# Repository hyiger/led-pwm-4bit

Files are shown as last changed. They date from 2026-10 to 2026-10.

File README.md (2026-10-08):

# led-pwm-4bit

A 40 × 30 mm two-layer board that dims a 24 V LED strip to one of 16 levels set by
four open-drain outputs of a Prusa GPIO Hackerboard. An ATtiny412 reads the 4-bit
word and drives a low-side N-MOSFET with 10-bit PWM at about 2.4 kHz.

KiCad 10 project. The design brief is [docs/spec.md](docs/spec.md) and the
reference netlist is [docs/netlist.txt](docs/netlist.txt).

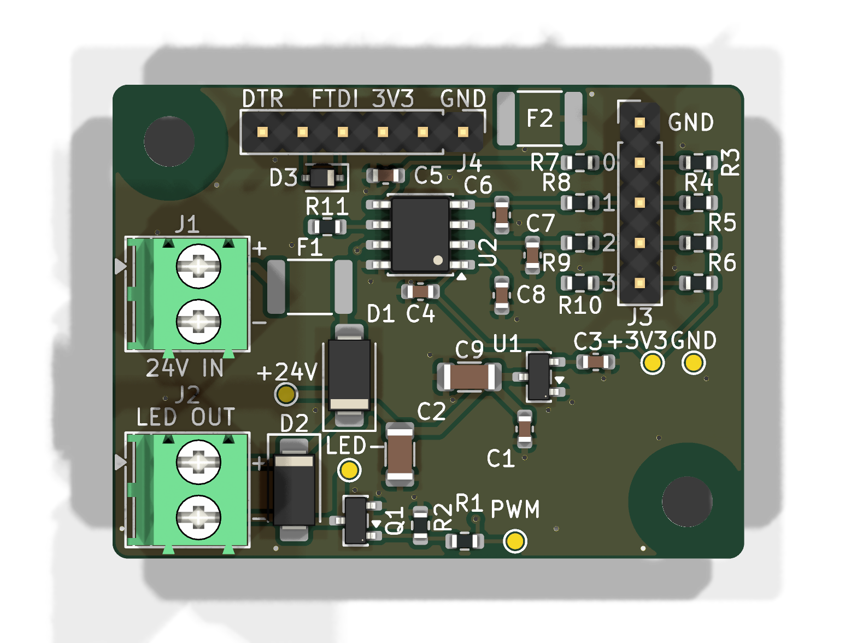
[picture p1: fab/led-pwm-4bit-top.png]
Top render


## Status

| Step | State |
|---|---|
| Schematic | Done. ERC: 0 violations. `check_netlist.py`: matches `docs/netlist.txt` |
| Placement | Done. Schematic parity clean |
| Routing | In progress. DRC: 0 violations; 5 unrouted connections (three `HB_GND` links to F2, UPDI_BUS R11–D3, SEL3 C8–R10). GND pours stitched with 32 vias |
| Parts | Every line has a manufacturer part carried by Mouser; see [Parts](#parts) |
| Firmware | Not started (spec section 9) |

## Files

| Path | Contents |
|---|---|
| `led-pwm-4bit.kicad_pro` | Project: JLCPCB constraints, net classes (Default, Power) |
| `led-pwm-4bit.kicad_sch` | Schematic, one sheet, KiCad standard symbols only |
| `led-pwm-4bit.kicad_pcb` | Board |
| `led-pwm-4bit.kicad_dru` | Custom DRC rules (JLCPCB limits, 0.5 mm power tracks) |
| `check_netlist.py` | Compares the schematic netlist with `docs/netlist.txt` |
| `scripts/export-fab.sh` | Runs ERC, netlist check and DRC, then writes `fab/` |
| `fab/` | Schematic PDF, BOM, Mouser order CSV, position file, renders; Gerbers once DRC is clean |

## Parts

All parts are chosen from manufacturers Mouser stocks, and each was checked against
its manufacturer's datasheet for package, pinout and ratings. Capacitor values were
also checked against DC-bias data.
`fab/led-pwm-4bit-bom.csv` is the full BOM and `fab/led-pwm-4bit-mouser-order.csv`
is in Mouser's BOM-tool format (`BOARDS=n scripts/export-fab.sh` scales it). The
order rounds the resistors, capacitors and D3 up to at least 10 with spares, which
costs less than the exact count at Mouser's single-piece prices.

The Mouser part-number column is left empty on purpose. Mouser blocks automated
access, so no Mouser number could be read off its live listing, and a guessed
number can import cleanly and still be the wrong part. Mouser's BOM tool matches
each line on the manufacturer part number instead. Once a Mouser number is
confirmed, add a field named `Mouser` to that symbol and the export carries it.

| Ref | Part | Notes |
|---|---|---|
| U1 | Microchip MCP1792T-3302H/CB | 55 V input LDO, SOT-23A |
| U2 | Microchip ATTINY412-SSN | Tube; ATtiny212-SSN also fits |
| Q1 | ROHM RTR030N05HZGTL | 45 V, RDS(on) ≤ 95 mΩ at VGS 2.5 V. The 60 V IRLML0060 is not rated below 4.5 V gate drive |
| D1, D2 | Diodes Inc B160-13-F | 60 V 1 A Schottky, SMA |
| D3 | onsemi BAT54HT1G | SOD-323, pin 1 cathode (BAT54J is out of stock at Mouser) |
| F1 | Littelfuse 1812L050/60MR | 0.5 A hold, 60 V, Imax 10 A |
| F2 | Bel Fuse 0ZCG0010FF2C | 0.1 A hold, 60 V, Imax 100 A; Hackerboard/programmer ground return |
| C1 | Murata GRM188R61H225KE11D | 2.2 µF 50 V X5R 0603, about 0.4 µF at 24 V |
| C2, C9 | Murata GRM31CR71H475MA12L | 4.7 µF 50 V X7R 1206, about 2.7 µF each at 24 V |
| C3 | Samsung CL10A106MP8NQWC | 10 µF 10 V X5R 0603, about 5.9 µF at 3.3 V |
| C4 | KEMET C0603C104K5RACTU | 100 nF 50 V X7R |
| C5–C8 | KEMET C0603C103K5RACTU | 10 nF 50 V X7R |
| R1–R11 | YAGEO RC0603FR-07…L | 1 % 0603; R3–R10 are all 10 kΩ |
| J1, J2 | Phoenix Contact 1984617 | PT 1,5/2-3,5-H, the part the footprint is drawn for |
| J3 | Würth 61300511121 | 1×5 2.54 mm header |
| J4 | Würth 61300611121 | 1×6 2.54 mm header |

No 10 µF 50 V X7R in 1206 was in stock at Mouser. The Murata 4.7 µF X7R keeps more
capacitance at 24 V than any 10 µF 1206 part Mouser stocks.

## Routing notes

- The Power net class (`+24V_IN`, `VIN_F`, `+24V`, `LED_NEG`, `GND`) defaults to
  0.5 mm, and DRC rejects anything narrower. Signals default to 0.25 mm.
- Rule areas keep tracks off B.Cu under Q1 and U2, so the bottom pour stays whole
  there (spec section 8). Ground vias are still allowed.
- Return Q1's source (pin 2) straight to the GND pad of C2.
- The pours are stitched with 32 GND vias (0.6/0.3 mm, tented): one beside each
  GND pad, two between C9 and U1, plus a sparse 8 mm grid. The +24V and +3V3
  tracks split the top pour into regions joined only by thin necks, and the vias
  tie every region to the bottom pour. The vias stay clear of the routes still to
  be drawn and of the mounting-hole keepout, and no via drill lands on
  silkscreen. A few via rings reach under the edge of a part outline; they are
  tented, so this is cosmetic.
- C6 pad 2 had only one thermal spoke because SEL1 and SEL2 crowd it. It now has a
  0.5 mm GND track to a via at (125.75, 108.75).
- `HB_GND` joins J3 pin 1, J4 pins 1–2 and F2 pad 1. A 0.25 mm track is enough,
  and it survives the brief fault current before F2 trips. J3.1 to J4.1 runs easily
  on B.Cu. Keep it out of the GND pour: F2 is the only connection between the two
  grounds.
- `scripts/export-fab.sh` refills the pours before its DRC, without saving the board.

## Wiring and mounting

- Fuse the 24 V feed at the source: a 2–3 A fast fuse (rated ≥ 32 V DC) in the +
  lead at the PSU or tap point, or a separate 1–2 A supply. F1 is rated to interrupt
  only 10 A and does not protect the J1 cable.
- Run the supply's − wire straight to J1 pin 2. Don't share it with the Hackerboard
  cable's ground, so only signal current flows through the Hackerboard ground.
- Check the strip wiring for a short between + and − before the first power-up.
- Mount the board on standoffs with nylon screws, or keep metal hardware away from any
  grounded frame. The mounting holes have no copper around them.
- Avoid hot-plugging J1 at 28 V with long leads (see Open items).

## Connectors

| | Pin 1 | Pin 2 | Pin 3 | Pin 4 | Pin 5 | Pin 6 |
|---|---|---|---|---|---|---|
| J1 24 V in | +24 V | GND | | | | |
| J2 LED strip | Strip + | Strip − | | | | |
| J3 Hackerboard J6 pins 1–5 | GND (via F2) | out0 | out1 | out2 | out3 | |
| J4 FTDI adapter | GND (via F2) | CTS (GND via F2) | VCC (n.c.) | TXD | RXD / UPDI | DTR (n.c.) |

Hackerboard J6 is a 1×10 2.54 mm footprint, usually bare holes. Its pin 1 is the
square pad by the `GND` label at the `0` end. A straight 1×5 cable from J6 pins 1–5
to J3 matches pin for pin.

## Flashing

J4 takes any USB-serial adapter in the standard FTDI pin order with **3.3 V logic**
(FT232R, CP2102, or a CH340 that really runs at 3.3 V). The SerialUPDI network
(D3 and R11) is on the board, so the adapter needs no modification.

1. Power the board from 24 V. J4's VCC pin is not connected.
2. Plug the adapter in with its GND on J4 pin 1 (the `GND` end of the header).
3. Flash with avrdude 8.x:

   ```bash
   avrdude -c serialupdi -p t412 -P /dev/cu.usbserial-XXXX -U flash:w:firmware.hex:i
   ```

   or pymcuprog:

   ```bash
   pymcuprog write -t uart -u /dev/cu.usbserial-XXXX -d attiny412 -f firmware.hex --erase --verify
   ```

Keep the default 115200 baud at 3.3 V. In the Arduino IDE with megaTinyCore, pick
"SerialUPDI - SLOW: 57600 baud", a 10 MHz clock and BOD 2.6 V. Never change the
UPDI/reset pin fuse: recovery would then need a 12 V programmer.

A Microchip programmer (Atmel-ICE, MPLAB SNAP, PICkit) connects to J4 pin 5 (UPDI)
and pin 1 (GND), with its target-voltage sense lead on TP2 (+3V3) and the board
powered from 24 V. Leave "power target from tool" off.

## Using it from the printer

```gcode
M267 R3 B0    ; once: all expander pins are outputs (firmware default)
M267 R1 B15   ; level 15 (full on); B0 = off, B1..B14 in between
```

The level persists in the printer's EEPROM. While the printer boots, or when the
cable is unplugged, the inputs float high and the strip is off.

## Checks

```bash
python3 check_netlist.py
```

```bash
scripts/export-fab.sh
```

The script runs ERC (`--severity-all --exit-code-violations`), the netlist check and
DRC with `--schematic-parity` after refilling the pours. It writes Gerbers and
separate plated and non-plated drill files only when DRC reports no violations and
no unrouted connections.

## Changes from spec Rev 0.1

- Resistors and small capacitors are 0603. The 47 µF electrolytic is replaced by two
  4.7 µF 50 V X7R 1206 MLCCs (C2, C9), because no 50 V bulk part exists in 0603.
- J4 is a 6-pin FTDI-style header with a SerialUPDI network (D3, R11 470 Ω)
  instead of a bare 3-pin UPDI header.
- SEL pins are permuted for a crossing-free layout: SEL0 = PA2, SEL1 = PA1,
  SEL2 = PA7, SEL3 = PA6. Section 6 of the spec allows this.
- Q1 is a ROHM RTR030N05HZGTL (45 V) instead of the AO3422 (55 V), which Mouser
  does not carry.
- F2 puts the Hackerboard and programmer grounds (net `HB_GND`) behind a 0.1 A PPTC,
  and R7–R10 are 10 kΩ instead of 1 kΩ.
- Board constraints follow JLCPCB's 2-layer 1 oz capabilities. The design net
  classes keep the spec's 0.2 mm clearance and 0.25 / 0.5 mm tracks.

## Open items

- **Reverse polarity with a shared ground.** D1 protects only the board's own +24V
  rail. If the supply shares ground with the printer and the J1 wires are swapped,
  board GND rises to supply +. F2 then trips and stops the short through the
  Hackerboard ground, and the 10 kΩ R7–R10 keep the current into the input pins to
  about 2.4 mA each. Two exposures remain:
  - The pull-ups R3–R6 draw up to about 11 mA out of +3V3, pulling it about 0.6 V
    below GND. That is past the U1 and U2 supply-pin limits. A Schottky clamp from GND
    to +3V3 would fix it.
  - A programming adapter plugged in at the same time sees 41–57 mA through R11, which
    burns R11 (0.8–1.5 W) and stresses U2's UPDI pin and the adapter. Check J1
    polarity before plugging in an adapter.
  A reverse-polarity MOSFET in the J1 return would remove both by keeping board GND
  from rising at all.
- **Strip short.** F1 protects the wiring and D1, not Q1. A short across J2 while the
  strip is lit can destroy Q1 (3 A continuous, 12 A for 10 µs). A failed Q1 usually
  shorts and leaves the strip on. Replace Q1 after any strip short.
- **Hot-plug overshoot.** The all-ceramic 24 V input rings when J1 is hot-plugged, and
  D1 holds the peak on +24V. At 24 V with leads of 2 m or less the first peak is about
  30–36 V. At 28 V with heavy leads and F1 near its minimum resistance it can reach
  45–50 V, above Q1's 45 V and the capacitors' 50 V rating. A 47 µF 50 V electrolytic
  on +24V would damp it to under 30 V.
- Prusa lists the Core One INDX as *not compatible* with the GPIO Hackerboard, although
  firmware 6.9.1 and 6.10.1 still enable the M262–M268 commands on it.
- JLCPCB charges a small-board fee when a side is 30 mm or less. 40 × 31 mm avoids it.

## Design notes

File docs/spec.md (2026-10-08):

# 4-Bit LED PWM Controller: KiCad Handoff Spec

Author: hyiger · Rev 0.4 · 2026-10-07

This is the complete brief for the KiCad project. The netlist in [`netlist.txt`](netlist.txt) is the source of truth; section 6 summarises it. Where this document and a datasheet disagree on a pin number, the datasheet wins: stop and report the conflict.

## 1. What to build

A small 2-layer board that dims a 24 V constant-voltage LED strip (about 120 mA) to one of 16 brightness levels. The level is a 4-bit word set by four open-drain outputs of a Prusa GPIO Hackerboard. An ATtiny412 reads the word and drives a low-side N-MOSFET with PWM.

```
24 V in ─ F1 ─ D1 ─┬──────────────── +24V ──── J2.1  strip +
                   ├─ C1, C2, C9                J2.2  strip − ─┐
                   └─ U1 (LDO) ─ +3V3 ─ U2 (ATtiny412)         │
Hackerboard pins 0–3 ─ J3 ─ pull-up + RC ─ U2 inputs           │
Hackerboard GND ─ J3.1 ─ F2 (PPTC) ─ board GND                  │
                                  U2 PA3 ─ R1 ─ gate Q1 ─ drain┘
USB-serial adapter ─ J4 ─ D3 + R11 (SerialUPDI) ─ U2 PA0/UPDI
```

The board takes only ground and four signals from the Hackerboard. It makes its own 3.3 V from the 24 V rail.

## 2. Hackerboard interface

- Pins 0–3 are open-drain N-MOSFET outputs (DMN3190LDW, 100 Ω gate resistor, 100 kΩ gate pull-down), rated by Prusa to switch 24 V at 500 mA to ground. They have no pull-ups, LEDs or clamps, so nothing on the Hackerboard can back-feed our 3.3 V pull-ups.
- Pins 4–7 are TCA6408A push-pull outputs at 3.3 V through 330 Ω (10 mA). This design does not use them.
- Logic is inverted at the wire: writing 1 turns the transistor on and pulls the pin to ground. Writing 0 leaves it floating.
- `M267 R1 B<0-255>` writes the whole output register in one I2C transaction. With the word on pins 0–3, `M267 R1 B0` to `M267 R1 B15` selects the level directly and all four bits change together. Bits 4–7 are written too.
- Run `M267 R3 B0` once so all pins are outputs (the firmware default). This also stops the 500 ms input polling that can trigger `btn_N` macros.
- Register values persist in the printer's EEPROM and are restored at boot. Until then the TCA6408A powers up with every pin as an input, so all four lines float and read as level 0.
- The Hackerboard must be connected when the printer boots; hot-plugging does not work.
- Connector: Hackerboard J6 is a 1×10 2.54 mm footprint, usually bare holes, so you will probably have to solder in a header. Its silkscreen reads `GND 7 6 5 4 3 2 1 0 GND`. Pin 1 is the square pad at the `0` end. J6 pins 1–5 carry GND, out0, out1, out2, out3 in that order and match J3 one to one.
- Out0–out2 also go to the Hackerboard's 2.5 mm "Shutter" jack. Leave that jack empty.
- Prusa's product page lists the Core One INDX as *not compatible* with the Hackerboard set, although firmware 6.9.1 and 6.10.1 still enable M262–M268 on COREONE_INDX. Check before relying on it with an INDX.

Consequence for this board: each input needs a pull-up to 3.3 V, and the firmware inverts the nibble. A disconnected or unpowered Hackerboard reads as 1111, which inverts to level 0, so the strip is off.

## 3. Electrical requirements

| Item | Requirement |
|---|---|
| Supply | 24 V DC nominal, 20–28 V operating, fused or current-limited at the source (2–3 A fast fuse rated ≥ 32 V DC, or a 1–2 A supply) |
| Load | Constant-voltage LED strip, 120 mA nominal; copper sized for 1 A |
| Switching | Low-side N-MOSFET, strip + tied to the protected 24 V rail |
| Levels | 16, gamma-corrected, level 0 fully off, level 15 fully on (100% duty) |
| PWM | 10-bit, about 2.44 kHz |
| Logic rail | 3.3 V from an on-board LDO, under 5 mA load |
| Default state | Strip off during reset, programming, and with inputs disconnected |
| Protection | Input fuse, reverse-polarity diode, clamp diode across the strip, PPTC in the Hackerboard/programmer ground return |
| Programming | SerialUPDI with any 3.3 V USB-serial adapter on J4, board powered from 24 V |

## 4. Circuit blocks

**Input and protection.** J1 → F1 (resettable fuse) → D1 (series Schottky, reverse-polarity protection) → `+24V`. F1 handles slow overloads: it holds 0.5 A, trips at 1 A, and needs up to 0.15 s at 8 A. It is rated to interrupt only 10 A, so the feed must be fused at the source (section 3); with that, D1 stays within its surge rating. F1 does not protect Q1: a short across J2 while the strip is lit can destroy Q1 before F1 trips. D1 protects only the board's own rail. When the supply shares ground with the printer, swapped J1 wires put supply + on board GND. The Hackerboard ground (J3 pin 1) and the programming adapter's ground (J4 pins 1 and 2) therefore reach board GND only through F2 (net `HB_GND`). F2 is a 0.1 A / 60 V PPTC rated to interrupt 100 A; its 1.6 Ω minimum resistance limits a 28 V short to 17.5 A until it trips. In normal use it carries only a few mA of signal return. Tripped, it still passes about 30 mA and leaves board GND up to 28 V above the printer's ground. C2 and C9 (4.7 µF 50 V X7R 1206 MLCCs, about 2.7 µF each at 24 V) are the bulk capacitance. C2 sits in the PWM loop beside Q1 and J2; C9 sits at U1's input. With no electrolytic, F1's resistance is the only damping of hot-plug ringing on the input, and D1 holds the peak on `+24V`. At 24 V with leads of 2 m or less the first peak is about 30–36 V. At 28 V with heavy leads and F1 near its 0.15 Ω minimum it can reach 45–50 V, above Q1's 45 V and the MLCCs' 50 V rating. A 47 µF 50 V electrolytic with 0.3–1 Ω ESR on `+24V` would hold it near 28 V.

**3.3 V rail.** U1 is an MCP1792-3302 (55 V input, 70 V transient, 100 mA) in SOT-23A. C1 is its input capacitor and C3 its output capacitor. All passives except C2 and C9 (1206) are 0603. The datasheet requires at least 2.2 µF of ceramic on the output and recommends 3.3 µF: C3 (10 µF 10 V X5R) keeps about 5.9 µF at 3.3 V. It recommends 2.2–10 µF on the input. No 0603 part rated 50 V holds much at 24 V: C1 (2.2 µF 50 V X5R) keeps about 0.4 µF, and C9 beside it adds about 2.7 µF. Dissipation is about (28 − 3.3) V × 5 mA ≈ 124 mW at the 28 V maximum, or 104 mW at 24 V nominal.

**MCU.** U2 is an ATtiny412 in SOIC-8, running at 10 MHz from its internal oscillator. C4 decouples it.

**Inputs.** Each of the four lines has a 10 kΩ pull-up to `+3V3` on the connector side, then 10 kΩ in series, then 10 nF to ground at the MCU pin (100 µs). With all four lines low the pull-ups draw 1.3 mA. The 10 kΩ series resistors also limit the current into the MCU pins to about 2.4 mA each if F2 trips and the board ground is lifted 24 V above the Hackerboard's. In that fault the pull-ups also draw up to about 11 mA out of `+3V3`, pulling it about 0.6 V below GND, past the U1 (−0.3 V) and U2 (−0.5 V) supply-pin limits (section 12).

**Output stage.** U2 PA3 → R1 (100 Ω) → gate of Q1. R2 (100 kΩ) holds the gate low while PA3 is high-impedance. Q1 is a ROHM RTR030N05HZGTL (45 V, RDS(on) ≤ 95 mΩ at VGS = 2.5 V, 3 A, TSMT3 on the SOT-23 land): about 11 mV drop and 1.4 mW at 120 mA. Its 45 V rating is the lowest on the 24 V side; the AO3422 (55 V) is not sold by Mouser, and no 55–60 V SOT-23 part in stock there has RDS(on) specified at 3.3 V or below. D2 clamps the drain to `+24V` to absorb wiring inductance.

**Programming.** J4 is a 6-pin FTDI-style header, numbered from the adapter's side. The adapter's TXD (pin 4) reaches the UPDI line through D3, a Schottky with its cathode toward TXD. The adapter's RXD (pin 5) connects to the UPDI line directly. R11 (470 Ω) sits between that line and PA0/UPDI. GND (pin 1) and CTS (pin 2) go to `HB_GND`, the ground behind F2, so CTS is asserted on adapters that enable handshaking by default. VCC (pin 3) is not connected, because some 3.3 V-logic adapters put 5 V there. DTR (pin 6) is not connected. A dedicated UPDI programmer uses pin 5 (UPDI) and pin 1 (GND). Microchip tools (Atmel-ICE, MPLAB SNAP, PICkit) also need their target-voltage sense lead on +3V3 (TP2), with the board powered from 24 V and "power target from tool" off.

## 5. BOM

All parts come from manufacturers Mouser stocks. Each was checked against its manufacturer's datasheet, and the capacitors against DC-bias data. Mouser availability was read from oemstrade.com on 2026-10-07, because Mouser blocks automated access. No Mouser part number is recorded until it has been read off its live listing; the order CSV matches on manufacturer part numbers.

| Ref | Manufacturer part | Package | Notes |
|---|---|---|---|
| U1 | Microchip MCP1792T-3302H/CB | SOT-23A-3 | Pin 1 GND, 2 VOUT, 3 VIN |
| U2 | Microchip ATTINY412-SSN | SOIC-8 (3.9 mm) | Tube. ATtiny212-SSN also fits |
| Q1 | ROHM RTR030N05HZGTL | TSMT3 (SOT-23 land) | Pin 1 G, 2 S, 3 D. 45 V, ≤ 95 mΩ at 2.5 V |
| D1, D2 | Diodes Inc B160-13-F | SMA | 60 V 1 A Schottky |
| D3 | onsemi BAT54HT1G | SOD-323 | Pin 1 K, 2 A. 30 V |
| F1 | Littelfuse 1812L050/60MR | 1812 | 0.5 A hold, 1 A trip, 60 V, Imax 10 A |
| F2 | Bel Fuse 0ZCG0010FF2C | 1812 | 0.1 A hold, 0.3 A trip, 60 V, Imax 100 A, Rmin 1.6 Ω. Fallback Bourns MF-MSMF010/60X-2 (40 A) |
| C1 | Murata GRM188R61H225KE11D, 2.2 µF 50 V X5R | 0603 | U1 input, about 0.4 µF at 24 V |
| C2, C9 | Murata GRM31CR71H475MA12L, 4.7 µF 50 V X7R | 1206 | Bulk, about 2.7 µF each at 24 V |
| C3 | Samsung CL10A106MP8NQWC, 10 µF 10 V X5R | 0603 | U1 output, about 5.9 µF at 3.3 V |
| C4 | KEMET C0603C104K5RACTU, 100 nF 50 V X7R | 0603 | U2 decoupling |
| C5–C8 | KEMET C0603C103K5RACTU, 10 nF 50 V X7R | 0603 | Input filters |
| R1 | YAGEO RC0603FR-07100RL, 100 Ω 1% | 0603 | Gate series |
| R2 | YAGEO RC0603FR-07100KL, 100 kΩ 1% | 0603 | Gate pull-down |
| R3–R6 | YAGEO RC0603FR-0710KL, 10 kΩ 1% | 0603 | Input pull-ups |
| R7–R10 | YAGEO RC0603FR-0710KL, 10 kΩ 1% | 0603 | Input series |
| R11 | YAGEO RC0603FR-07470RL, 470 Ω 1% | 0603 | UPDI series |
| J1, J2 | Phoenix Contact 1984617 (PT 1,5/2-3,5-H) | THT | 24 V in, strip out |
| J3 | Würth 61300511121, 1×5 2.54 mm | THT | Hackerboard |
| J4 | Würth 61300611121, 1×6 2.54 mm | THT | FTDI / SerialUPDI |
| TP1–TP5 | Test point | 1 mm pad | +24V, +3V3, GND, PWM, LED− |
| H1, H2 | M3 mounting hole, 3.2 mm | NPTH | No net |

Diode pin numbers follow the KiCad convention: pin 1 cathode, pin 2 anode.

## 6. Netlist

[`netlist.txt`](netlist.txt) lists every net. `check_netlist.py` compares the schematic against it. Compared with Rev 0.1:

```netlist
+24V:     ... C2.1 C9.1 ...         (C9 added)
UPDI:     U2.6 R11.2
UPDI_BUS: J4.5 R11.1 D3.2
UPDI_TX:  J4.4 D3.1
GND:      ... C2.2 C9.2 ... F2.2 ...  (J3.1, J4.1, J4.2 moved to HB_GND)
HB_GND:   J3.1 J4.1 J4.2 F2.1      (J4.2 = CTS)
+3V3:     ... (J4 no longer on +3V3)
NC:       J4.3 J4.6
SEL0:     R7.2 C5.1 U2.5         (PA2)
SEL1:     R8.2 C6.1 U2.4         (PA1)
SEL2:     R9.2 C7.1 U2.3         (PA7)
SEL3:     R10.2 C8.1 U2.2        (PA6)
```

U2 pin map (ATtiny412 SOIC-8): 1 VDD, 2 PA6, 3 PA7, 4 PA1, 5 PA2, 6 PA0/UPDI, 7 PA3, 8 GND. `PWM` stays on PA3 (TCA0 WO0, the default pin; the alternate is PA7).

## 7. Connectors

| Connector | Pin 1 | Pin 2 | Pin 3 | Pin 4 | Pin 5 | Pin 6 |
|---|---|---|---|---|---|---|
| J1, 24 V in | +24 V | GND | | | | |
| J2, strip | Strip + | Strip − | | | | |
| J3, Hackerboard J6 pins 1–5 | GND (through F2) | Pin 0 (bit 0) | Pin 1 (bit 1) | Pin 2 (bit 2) | Pin 3 (bit 3) | |
| J4, FTDI adapter | GND (through F2) | CTS (to GND through F2) | VCC (n.c.) | TXD (adapter out) | RXD (adapter in) = UPDI | DTR (n.c.) |

Program with the board powered from 24 V. Never connect the board's 3.3 V to the adapter's VCC.

## 8. PCB constraints

- 2 layers, 1.6 mm FR4, 1 oz copper, outline 40 × 30 mm, two M3 holes with no copper within 3.75 mm of their centres, so metal mounting hardware cannot reach board GND. JLCPCB adds a small-board fee when a side is 30 mm or less; 40 × 31 mm avoids it.
- Board Setup > Constraints holds JLCPCB's 2-layer 1 oz absolute minimums: 0.10 mm clearance, track and connection width, 0.05 mm via annular ring, 0.25 mm via diameter, 0.15 mm drill, 0.2 mm hole-to-hole, 0.2 mm copper-to-hole, 0.2 mm copper-to-edge, silk text 1.0 mm high with 0.15 mm stroke. Solder mask: 0 expansion, 0.1 mm minimum web, 0.09 mm mask to copper.
- `led-pwm-4bit.kicad_dru` adds the JLCPCB limits those fields cannot express: PTH ring ≥ 0.18 mm, PTH hole to copper ≥ 0.28 mm, pad hole to hole ≥ 0.45 mm, NPTH ≥ 0.5 mm, pad to silkscreen ≥ 0.15 mm.
- Net classes carry the design values. Default: 0.2 mm clearance, 0.25 mm track, 0.6/0.3 mm via. Power (`+24V_IN`, `VIN_F`, `+24V`, `LED_NEG`, `GND`): 0.5 mm track, enforced as a DRC minimum.
- Ground pour on both layers, stitched with vias. Rule areas keep tracks off B.Cu under Q1 and U2 so the bottom pour stays unbroken there.
- Keep the PWM current loop small: C2, J2, Q1 and D2 together, with Q1's source returning to C2's negative pin by the shortest path.
- C1 within 3 mm of U1 pin 3. C3 within 3 mm of U1 pin 2. C4 directly at U2 pins 1 and 8. C5–C8 at the U2 pins, R3–R6 near J3.
- J1 and J2 on one edge, J3 on the opposite edge, J4 on the top edge for the adapter.
- Silkscreen: polarity at J1 and J2, `GND 0 1 2 3` at J3, adapter pin names at J4, board name, revision, and "hyiger".

## 9. Firmware contract (phase 2)

- Clock: internal 20 MHz oscillator, prescaler 2, giving 10 MHz. This is the limit at 3.3 V. The part starts at 20 MHz / 6 after reset.
- BOD: BODLEVEL2 (2.6 V). The 10 MHz speed grade is guaranteed only down to that level. Never use 4.2 V; chip erase would then fail at 3.3 V.
- Fuses: never change SYSCFG0.RSTPINCFG from UPDI. GPIO or RESET locks out SerialUPDI, and recovery then needs a 12 V high-voltage programmer.
- PWM: TCA0 single-slope on WO0 (PA3), PORTMUX.CTRLC = 0, prescaler 4, PER = 1022. Frequency is 10 MHz / 4 / 1023 = 2444 Hz. A compare value of 1023 gives a constant high output. Do not use split mode.
- Inputs: PA2, PA1, PA7, PA6 as plain inputs (external pull-ups, internal ones off). PA0 stays UPDI.
- Mapping: SEL0 = PA2, SEL1 = PA1, SEL2 = PA7, SEL3 = PA6.
- Level: `level = ~(bit3..bit0) & 0x0F`, with bit 0 = SEL0.
- Debounce: sample every 1 ms and apply a new level only after 20 identical consecutive samples.
- Start-up: set compare to 0 before enabling the PA3 output.
- Lookup table (gamma 2.2, 10-bit):

```c
static const uint16_t LUT[16] = {
    0, 3, 12, 30, 56, 91, 136, 191, 257, 333, 419, 517, 626, 747, 879, 1023
};
```

Level 1 is a 1.2 µs pulse. If it is unstable or invisible on the real strip, raise `LUT[1]` or use a larger timer prescaler. The hardware does not change.

Flashing with avrdude 8.x (7.x chip-erases on every flash write):

```
avrdude -c serialupdi -p t412 -P <port> -U flash:w:firmware.hex:i
```

Keep the default 115200 baud at 3.3 V. In the Arduino IDE with megaTinyCore, use "SerialUPDI - SLOW: 57600 baud", a 10 MHz clock and BOD 2.6 V.

## 10. KiCad workflow and deliverables

1. Target the installed KiCad, checked with `kicad-cli version` (10.0.7).
2. Project name `led-pwm-4bit`. Every symbol and footprint comes from the KiCad standard libraries with pin numbers checked against the datasheets (Q1 uses `Transistor_FET:Q_NMOS_GSD`: 1 G, 2 S, 3 D).
3. `check_netlist.py` exports the netlist with `kicad-cli sch export netlist` and compares it to `netlist.txt`. It must match exactly: same nets, same pins, nothing extra.
4. `kicad-cli sch erc --severity-all --exit-code-violations` and `kicad-cli pcb drc --schematic-parity --severity-all` must report zero violations.
5. Review points: after the schematic passes ERC and the netlist check; after placement; after routing passes DRC.
6. `scripts/export-fab.sh` writes the outputs to `fab/`: schematic PDF, BOM, Mouser BOM-tool order CSV, position file, top and bottom renders, and, once DRC is clean, Gerbers and separate PTH/NPTH drill files zipped for upload.

## 11. Acceptance checks

- Exported netlist equals `netlist.txt`. ERC and DRC report zero violations.
- No unconnected pins except J4.3 and J4.6, which carry no-connect flags. No pin on more than one net.
- Every polarized part (D1, D2, D3, Q1, U1, U2) has its pin 1 checked against the datasheet and the footprint.
- With U2 removed or in reset, `GATE` is held at 0 V by R2.
- Voltage ratings: everything on `+24V_IN`, `VIN_F`, `+24V` or `LED_NEG` is rated at least 35 V.

## 12. Open items

Resolved:

- Reverse polarity through a shared ground: F2 in the J3/J4 ground return (section 4), with R7–R10 raised to 10 kΩ.
- Hackerboard connector: J6, 1×10 2.54 mm. Pins 1–5 = GND, 0, 1, 2, 3, so J3 is a 1×5 2.54 mm header.
- TCA0 WO0 defaults to PA3 (ATtiny212/412 datasheet DS40002287A, Table 5-2 and PORTMUX.CTRLC).
- F1: Littelfuse 1812L050/60MR (60 V, 0.5 A hold).
- Q1 pin order: ROHM's RTR030N05HZG datasheet gives (1) Gate, (2) Source, (3) Drain.

Still open:

- Core One INDX compatibility of the Hackerboard (see section 2).
- Mouser part numbers: to be read off Mouser's live listings, or resolved by uploading the order CSV to Mouser's BOM tool.
- With F2 tripped the board ground floats up to 28 V above the printer's. R7–R10 limit the input pins to about 2.4 mA each, but:
  - the pull-ups R3–R6 pull `+3V3` about 0.6 V below GND at up to 11 mA. A low-VF Schottky from GND to `+3V3` (Microchip DS20006229 section 4.4) would clamp it;
  - a programming adapter on J4 at the same time sees 41–57 mA through R11 and D3. That burns R11 (0.8–1.5 W) and drives U2's UPDI pin below GND. Check J1 polarity before plugging in an adapter.
  A low-side reverse-polarity MOSFET in the J1 return would stop board GND rising at all and remove both cases.
- A short across J2 while Q1 conducts can destroy Q1 before F1 trips; a failed Q1 usually shorts and leaves the strip on. Check the strip wiring before the first power-up and replace Q1 after any strip short.
- Hot-plug overshoot at 28 V with heavy leads can exceed Q1's 45 V (section 4). Avoid hot-plugging J1 at 28 V, or add a damped electrolytic.
- Bel's 100 A rating for F2 is unusually high for its size (Littelfuse's equivalent is rated 10 A at 60 V); Bel's datasheet, product page and the Fuzetec original all state 100 A. The Bourns fallback is rated 40 A.
- Strip current: above 0.5 A, F1 and D1 have to change.
- Where the 24 V comes from. If it is not the printer's own supply, the two grounds still have to be common through J3 pin 1. Run the supply's − wire straight to J1 pin 2 and keep it separate from the Hackerboard cable's ground, so only signal current flows through the Hackerboard ground.

Left out on purpose: a TVS on the 24 V input (an SMAJ28A-class part still lets 44–47 V through at 28 V, so it would not protect Q1), a status LED (no spare MCU pin), and any isolation between the printer and the strip.

## 13. Sources

- Prusa help article "GPIO Hackerboard" and schematic FDM-MK4-Gpio-02 (BOM05): connector, output stage, G-code.
- Prusa-Firmware-Buddy v6.9.1/v6.10.1, `src/marlin_stubs/M262-M268.cpp`, `src/hw/TCA6408A.cpp`: M267 behaviour and EEPROM persistence.
- Microchip DS20006229D, MCP1792/3: SOT-23A pinout, capacitor requirements, 4.5–55 V input.
- ROHM RTR030N05HZG datasheet Rev.001: 45 V, RDS(on) ≤ 95 mΩ at VGS = 2.5 V, ±12 V gate, pinout.
- Murata, Samsung and KEMET DC-bias data for C1, C2/C9 and C3.
- Microchip DS40002287A, ATtiny212/214/412/414/416: pinout, multiplexing, speed grades, UPDI.
- JLCPCB PCB capabilities page (checked 2026-10-07).
- SpenceKonde AVR-Guidance `UPDI/jtag2updi.md` and the avrdude 8.3 manual: SerialUPDI wiring and commands.

## Revision history

- 0.4 (2026-10-07): F2 (PPTC) in the Hackerboard and programmer ground return (net `HB_GND`); R7–R10 raised to 10 kΩ; copper keepout around the mounting holes; source fusing required; fault limits documented after an adversarial review.
- 0.3 (2026-10-07): Parts sourced from Mouser (Q1 ROHM RTR030N05HZGTL, D3 BAT54HT1G on SOD-323, F1 Littelfuse, J1/J2 Phoenix 1984617, Würth headers, Yageo/KEMET/Murata/Samsung passives); the 47 µF electrolytic replaced by C2 and C9 (4.7 µF 50 V X7R 1206); JLCPCB assembly files dropped.
- 0.2 (2026-10-07): 0603 passives throughout; J4 changed to an FTDI-style SerialUPDI header with D3 and R11; SEL pins permuted for routing; JLCPCB rules; parts selected with LCSC numbers; open items from 0.1 resolved.
- 0.1 (2026-10-07): first handoff.

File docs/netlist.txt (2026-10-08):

# Reference netlist for led-pwm-4bit. check_netlist.py compares the
# schematic's exported netlist against this file.
#
# Format: NET: REF.PIN ...   Every pin of every part except H1 and H2
# appears exactly once. "NC:" lists pins that must stay unconnected.
#
# Differs from spec Rev 0.1 section 6 in four places:
# - The Hackerboard and programming-adapter grounds (J3.1, J4.1, J4.2) reach
#   board GND through F2, a PPTC that opens if J1 is wired backwards while
#   the supply shares ground with the printer.
# - The 47 uF electrolytic C2 is replaced by two 1206 MLCCs, C2 and C9.
# - J4 is a 6-pin FTDI-style header with an on-board SerialUPDI network
#   (D3, R11) instead of a 3-pin UPDI header.
# - SEL0..SEL3 use the permutation section 6 allows, so the four input
#   rows from J3 reach U2 without crossing: SEL0 = PA2, SEL1 = PA1,
#   SEL2 = PA7, SEL3 = PA6.

+24V_IN: J1.1 F1.1
VIN_F:   F1.2 D1.2
+24V:    D1.1 C1.1 C2.1 C9.1 U1.3 D2.1 J2.1 TP1.1
GND:     J1.2 C1.2 C2.2 C9.2 U1.1 C3.2 C4.2 U2.8 R2.2 Q1.2 F2.2 C5.2 C6.2 C7.2 C8.2 TP3.1
HB_GND:  J3.1 J4.1 J4.2 F2.1
+3V3:    U1.2 C3.1 C4.1 U2.1 R3.1 R4.1 R5.1 R6.1 TP2.1
UPDI:     U2.6 R11.2
UPDI_BUS: J4.5 R11.1 D3.2
UPDI_TX:  J4.4 D3.1
PWM:     U2.7 R1.1 TP4.1
GATE:    R1.2 R2.1 Q1.1
LED_NEG: Q1.3 D2.2 J2.2 TP5.1
IN0:     J3.2 R3.2 R7.1
IN1:     J3.3 R4.2 R8.1
IN2:     J3.4 R5.2 R9.1
IN3:     J3.5 R6.2 R10.1
SEL0:    R7.2 C5.1 U2.5
SEL1:    R8.2 C6.1 U2.4
SEL2:    R9.2 C7.1 U2.3
SEL3:    R10.2 C8.1 U2.2
NC:      J4.3 J4.6

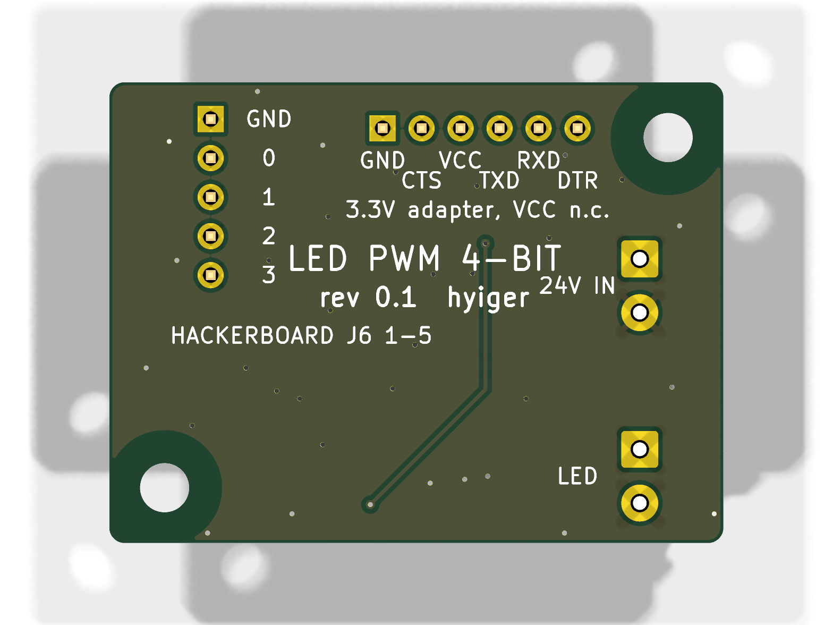
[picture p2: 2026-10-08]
fab/led-pwm-4bit-bottom.png

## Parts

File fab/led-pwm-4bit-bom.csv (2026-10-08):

Reference | Value | Footprint | Manufacturer | MPN | Mouser | Qty
C1 | 2.2u 50V X5R | Capacitor_SMD:C_0603_1608Metric | Murata | GRM188R61H225KE11D |  | 1
C2,C9 | 4.7u 50V X7R | Capacitor_SMD:C_1206_3216Metric | Murata | GRM31CR71H475MA12L |  | 2
C3 | 10u 10V X5R | Capacitor_SMD:C_0603_1608Metric | Samsung | CL10A106MP8NQWC |  | 1
C4 | 100n 50V X7R | Capacitor_SMD:C_0603_1608Metric | KEMET | C0603C104K5RACTU |  | 1
C5-C8 | 10n 50V X7R | Capacitor_SMD:C_0603_1608Metric | KEMET | C0603C103K5RACTU |  | 4
D1,D2 | B160 | Diode_SMD:D_SMA | Diodes Inc | B160-13-F |  | 2
D3 | BAT54HT1G | Diode_SMD:D_SOD-323 | onsemi | BAT54HT1G |  | 1
F1 | 0.5A 60V | Fuse:Fuse_1812_4532Metric | Littelfuse | 1812L050/60MR |  | 1
F2 | 0.1A 60V | Fuse:Fuse_1812_4532Metric | Bel Fuse | 0ZCG0010FF2C |  | 1
J1 | 24V IN | TerminalBlock_Phoenix:TerminalBlock_Phoenix_PT-1,5-2-3.5-H_1x02_P3.50mm_Horizontal | Phoenix Contact | 1984617 |  | 1
J2 | LED STRIP | TerminalBlock_Phoenix:TerminalBlock_Phoenix_PT-1,5-2-3.5-H_1x02_P3.50mm_Horizontal | Phoenix Contact | 1984617 |  | 1
J3 | HACKERBOARD | Connector_PinHeader_2.54mm:PinHeader_1x05_P2.54mm_Vertical | Wurth Elektronik | 61300511121 |  | 1
J4 | FTDI-UPDI | Connector_PinHeader_2.54mm:PinHeader_1x06_P2.54mm_Vertical | Wurth Elektronik | 61300611121 |  | 1
Q1 | RTR030N05HZG | Package_TO_SOT_SMD:SOT-23 | ROHM | RTR030N05HZGTL |  | 1
R1 | 100 | Resistor_SMD:R_0603_1608Metric | YAGEO | RC0603FR-07100RL |  | 1
R2 | 100k | Resistor_SMD:R_0603_1608Metric | YAGEO | RC0603FR-07100KL |  | 1
R3-R10 | 10k | Resistor_SMD:R_0603_1608Metric | YAGEO | RC0603FR-0710KL |  | 8
R11 | 470 | Resistor_SMD:R_0603_1608Metric | YAGEO | RC0603FR-07470RL |  | 1
U1 | MCP1792T-3302H/CB | Package_TO_SOT_SMD:SOT-23 | Microchip | MCP1792T-3302H/CB |  | 1
U2 | ATtiny412-SSN | Package_SO:SOIC-8_3.9x4.9mm_P1.27mm | Microchip | ATTINY412-SSN |  | 1

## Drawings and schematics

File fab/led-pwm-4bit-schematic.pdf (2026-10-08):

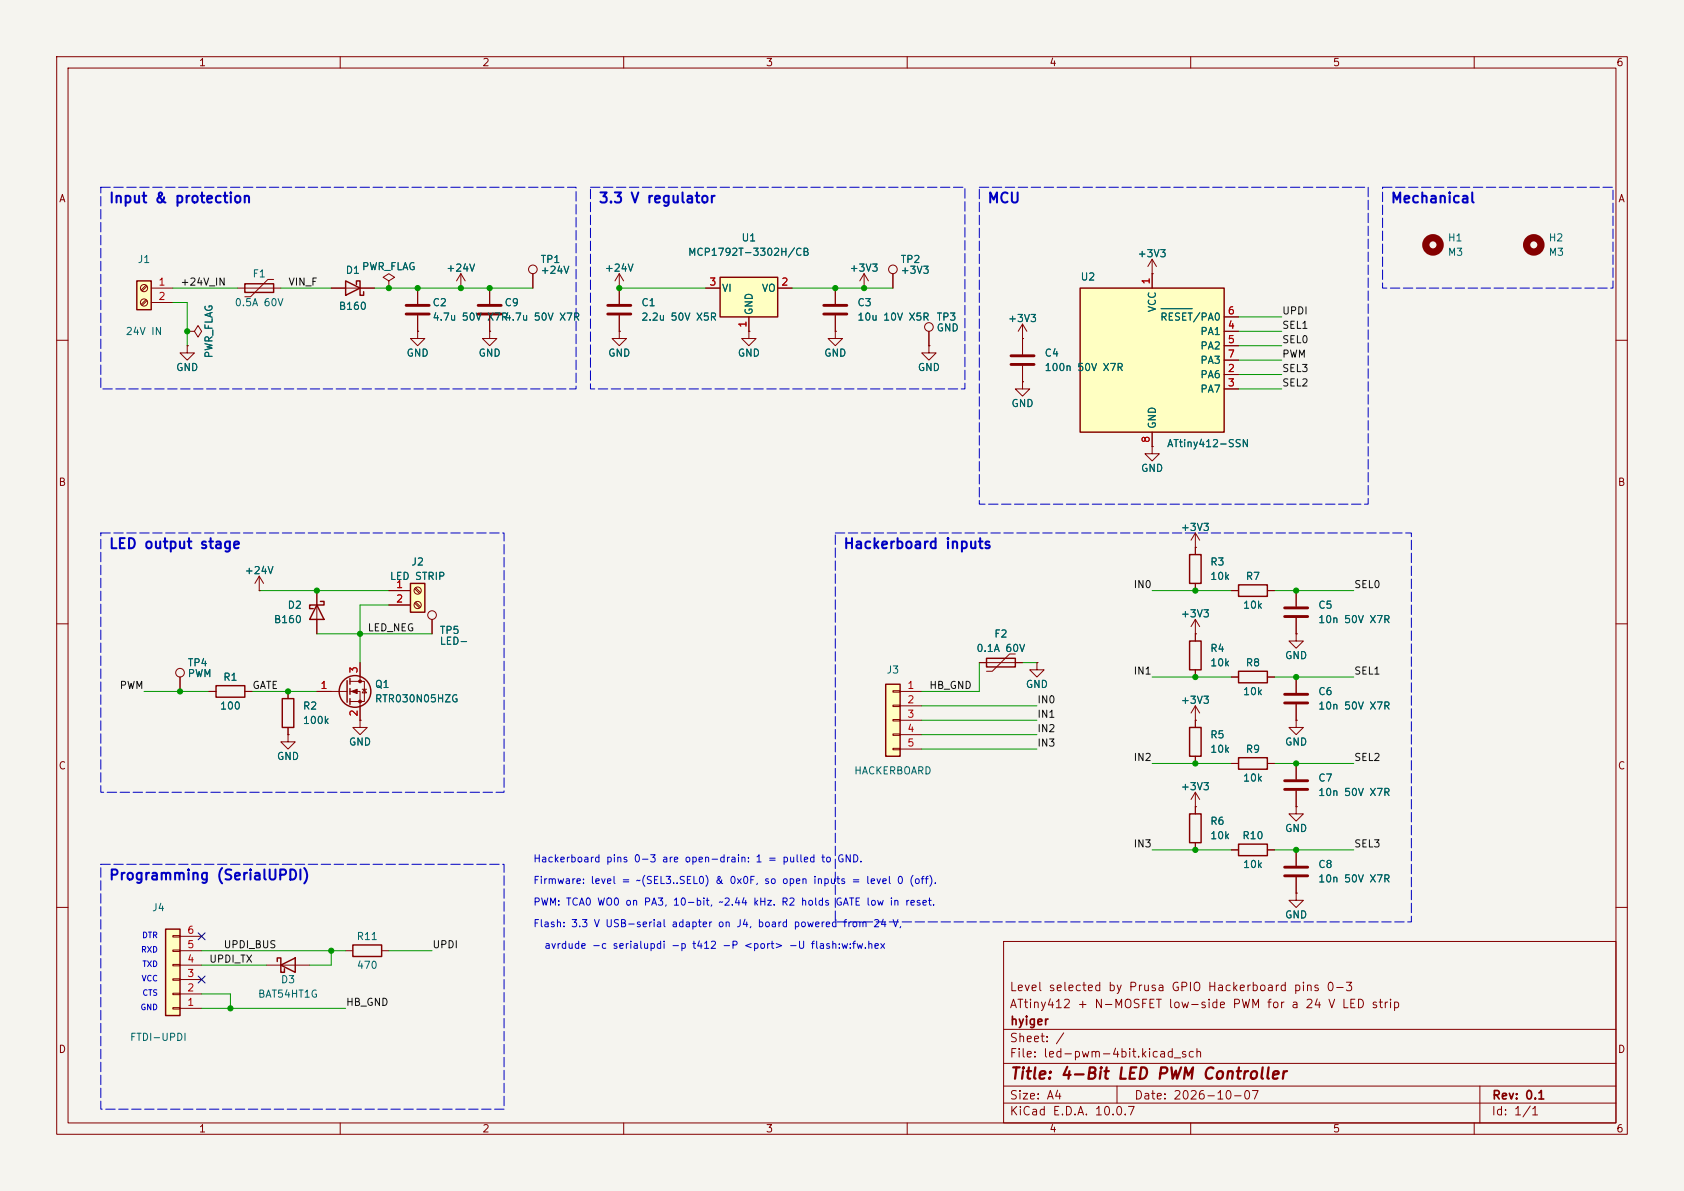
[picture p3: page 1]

Level selected by Prusa GPIO Hackerboard pins 0-3 +3V3 C3

Firmware: level = ~(SEL3..SEL0) & 0x0F, so open inputs = level 0 (off). avrdude -c serialupdi -p t412 -P <port> -U flash:w:fw.hex

ATtiny412 + N-MOSFET low-side PWM for a 24 V LED strip
hyiger
Sheet: /
File: led-pwm-4bit.kicad_sch
Title: 4-Bit LED PWM Controller

Size: A4 | Rev: 0.1
KiCad E.D.A. 10.0.7 | Id: 1/1

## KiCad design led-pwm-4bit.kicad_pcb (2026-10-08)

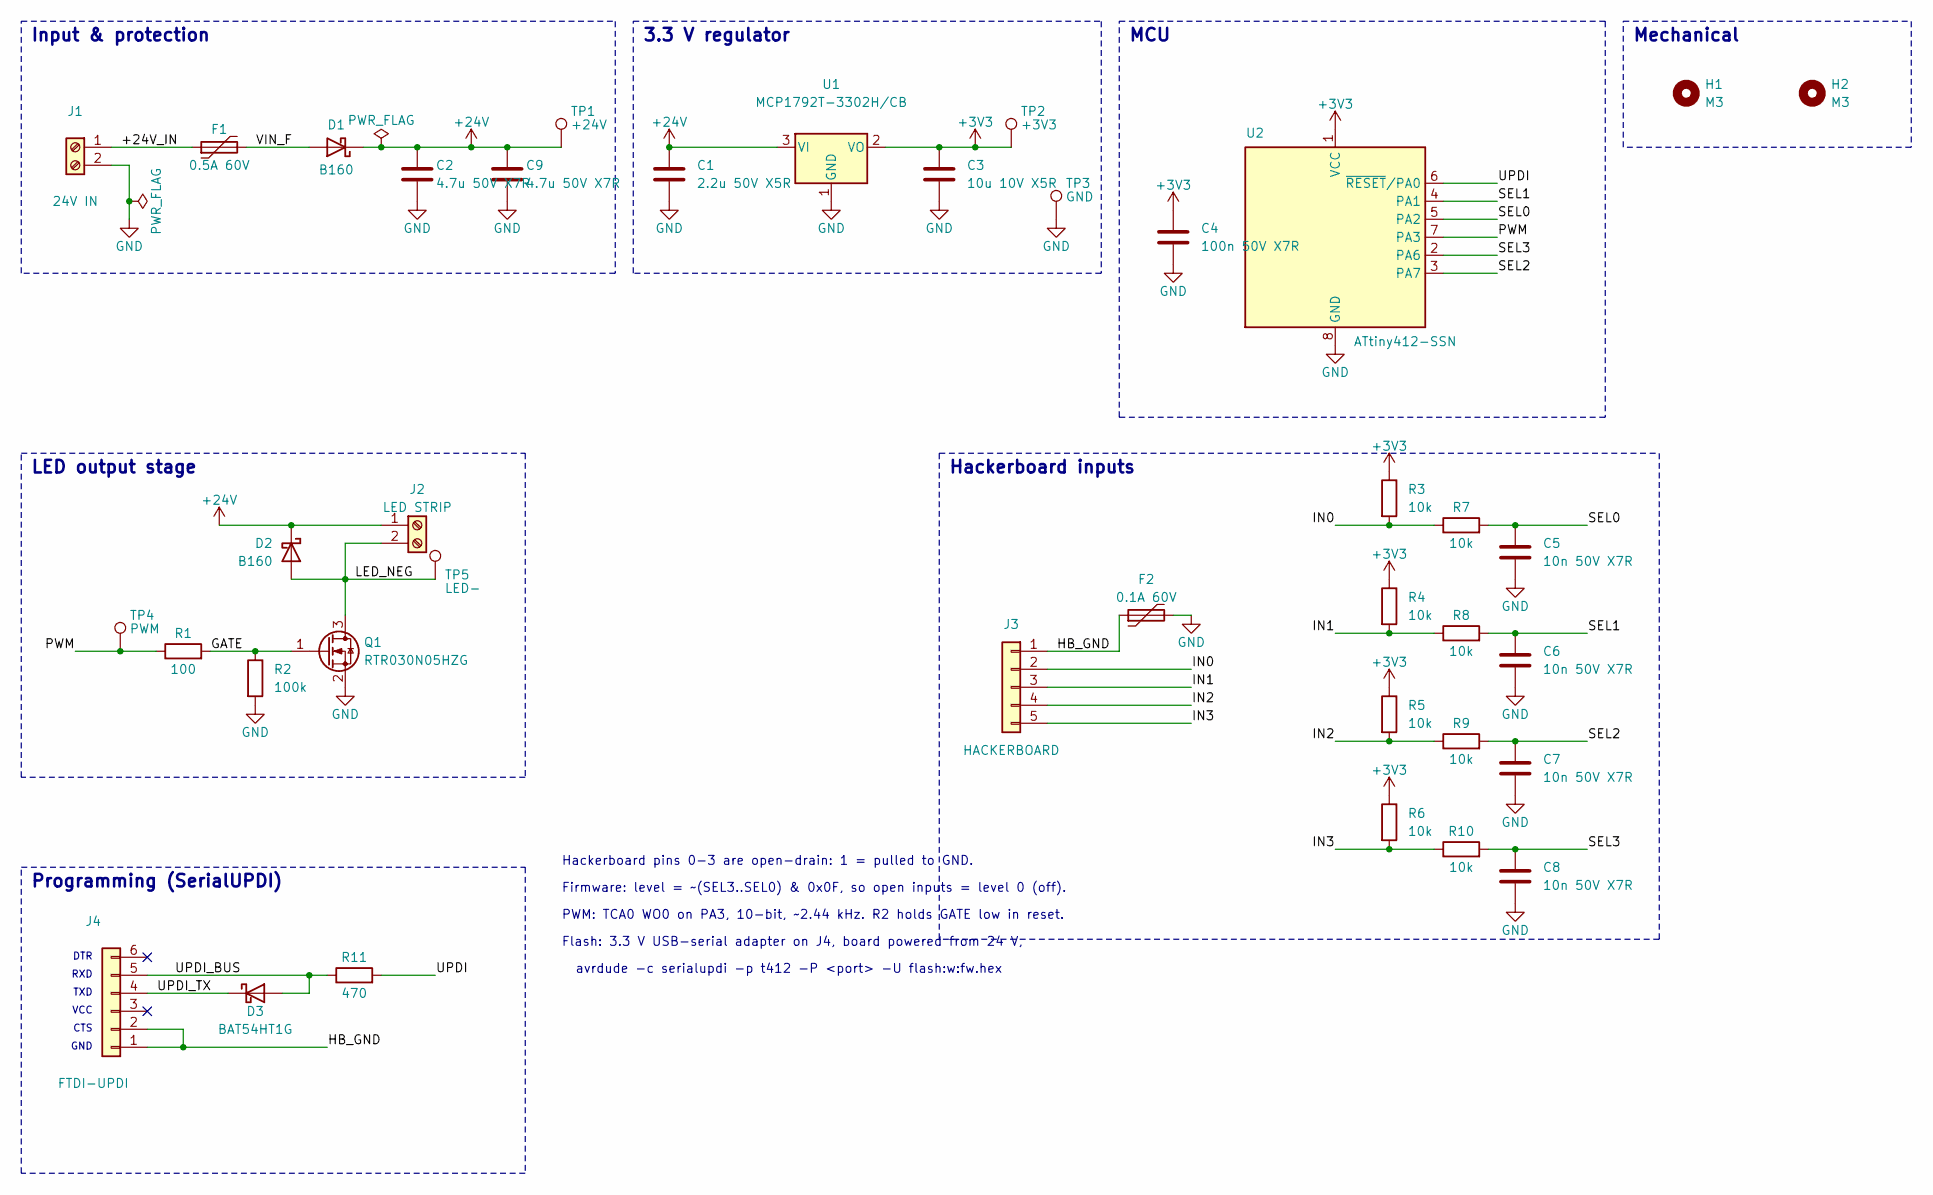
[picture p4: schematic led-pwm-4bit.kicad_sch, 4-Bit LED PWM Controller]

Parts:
C1: 2.2u 50V X5R; C_0603_1608Metric; MPN GRM188R61H225KE11D
C2, C9: 4.7u 50V X7R; C_1206_3216Metric; MPN GRM31CR71H475MA12L
C3: 10u 10V X5R; C_0603_1608Metric; MPN CL10A106MP8NQWC
C4: 100n 50V X7R; C_0603_1608Metric; MPN C0603C104K5RACTU
C5, C6, C7, C8: 10n 50V X7R; C_0603_1608Metric; MPN C0603C103K5RACTU
D1, D2: B160; D_SMA; MPN B160-13-F
D3: BAT54HT1G; D_SOD-323; MPN BAT54HT1G
F1: 0.5A 60V; Fuse_1812_4532Metric; MPN 1812L050/60MR
F2: 0.1A 60V; Fuse_1812_4532Metric; MPN 0ZCG0010FF2C
H1, H2: M3; MountingHole_3.2mm_M3
J1: 24V IN; TerminalBlock_Phoenix_PT-1,5-2-3.5-H_1x02_P3.50mm_Horizontal; MPN 1984617
J2: LED STRIP; TerminalBlock_Phoenix_PT-1,5-2-3.5-H_1x02_P3.50mm_Horizontal; MPN 1984617
J3: HACKERBOARD; PinHeader_1x05_P2.54mm_Vertical; MPN 61300511121
J4: FTDI-UPDI; PinHeader_1x06_P2.54mm_Vertical; MPN 61300611121
Q1: RTR030N05HZG; SOT-23; MPN RTR030N05HZGTL
R1: 100; R_0603_1608Metric; MPN RC0603FR-07100RL
R2: 100k; R_0603_1608Metric; MPN RC0603FR-07100KL
R3, R4, R5, R6, R7, R8, R9, R10: 10k; R_0603_1608Metric; MPN RC0603FR-0710KL
R11: 470; R_0603_1608Metric; MPN RC0603FR-07470RL
TP1: +24V; TestPoint_Pad_D1.0mm
TP2: +3V3; TestPoint_Pad_D1.0mm
TP3: GND; TestPoint_Pad_D1.0mm
TP4: PWM; TestPoint_Pad_D1.0mm
TP5: LED-; TestPoint_Pad_D1.0mm
U1: MCP1792T-3302H/CB; SOT-23; MPN MCP1792T-3302H/CB
U2: ATtiny412-SSN; SOIC-8_3.9x4.9mm_P1.27mm; MPN ATTINY412-SSN

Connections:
+3V3: C3.1, C4.1, R3.1, R4.1, R5.1, R6.1, TP2.1, U1.2 (VO), U2.1 (VCC)
+24V: C1.1, C2.1, C9.1, D1.1 (K), D2.1 (K), J2.1, TP1.1, U1.3 (VI)
/+24V_IN: F1.1, J1.1
/GATE: Q1.1 (G), R1.2, R2.1
/HB_GND: F2.1, J3.1, J4.1, J4.2
/IN0: J3.2, R3.2, R7.1
/IN1: J3.3, R4.2, R8.1
/IN2: J3.4, R5.2, R9.1
/IN3: J3.5, R6.2, R10.1
/LED_NEG: D2.2 (A), J2.2, Q1.3 (D), TP5.1
/PWM: R1.1, TP4.1, U2.7 (PA3)
/SEL0: C5.1, R7.2, U2.5 (PA2)
/SEL1: C6.1, R8.2, U2.4 (PA1)
/SEL2: C7.1, R9.2, U2.3 (PA7)
/SEL3: C8.1, R10.2, U2.2 (PA6)
/UPDI: R11.2, U2.6 (~RESET/PA0)
/UPDI_BUS: D3.2 (A), J4.5, R11.1
/UPDI_TX: D3.1 (K), J4.4
/VIN_F: D1.2 (A), F1.2
GND: C1.2, C2.2, C3.2, C4.2, C5.2, C6.2, C7.2, C8.2, C9.2, F2.2, J1.2, Q1.2 (S), R2.2, TP3.1, U1.1 (GND), U2.8 (GND)

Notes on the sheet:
MCU
TXD
Flash: 3.3 V USB-serial adapter on J4, board powered from 24 V,
Mechanical
Hackerboard pins 0-3 are open-drain: 1 = pulled to GND.
PWM: TCA0 WO0 on PA3, 10-bit, ~2.44 kHz. R2 holds GATE low in reset.
avrdude -c serialupdi -p t412 -P <port> -U flash:w:fw.hex
RXD
3.3 V regulator
Programming (SerialUPDI)
DTR
VCC
Input & protection
Firmware: level = ~(SEL3..SEL0) & 0x0F, so open inputs = level 0 (off).
CTS
GND
LED output stage
Hackerboard inputs

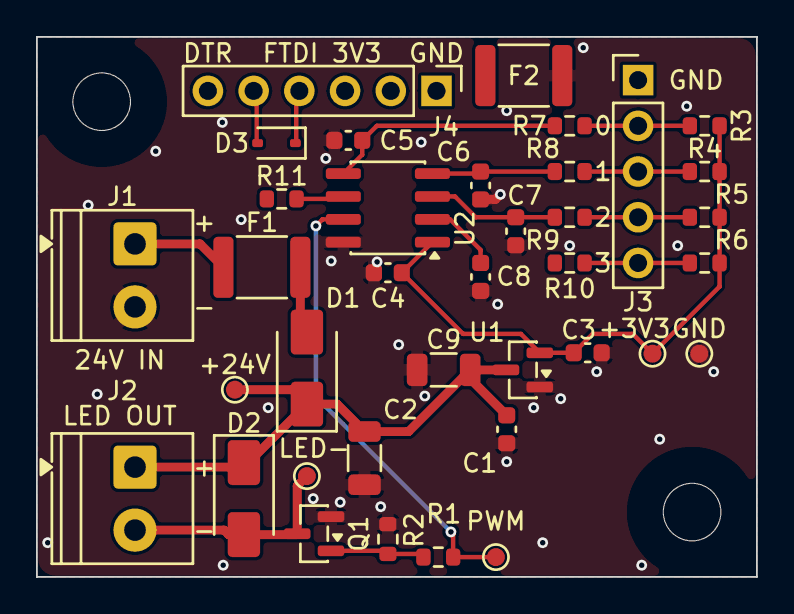
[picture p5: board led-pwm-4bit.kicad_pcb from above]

Board: 2 copper layers, 40.0 x 30.0 mm, 39 parts (0 on the bottom side), 20 nets.

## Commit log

2026-10-07 Add 4-bit LED PWM controller KiCad project
    KiCad 10 project for a 40 x 30 mm two-layer board that dims a 24 V LED
    strip to one of 16 levels set by four open-drain outputs of a Prusa
    GPIO Hackerboard. An ATtiny412 reads the word and drives a low-side
    N-MOSFET with 10-bit PWM.
    - Schematic passes ERC and matches docs/netlist.txt (check_netlist.py).
    - Board uses JLCPCB 2-layer constraints plus custom DRC rules; placed
    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
    [led-pwm-4bit-bom.csv, led-pwm-4bit-mouser-order.csv, led-pwm-4bit.kicad_pcb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]
2026-10-08 Fuse the Hackerboard ground return and address review findings
    Swapped J1 wires on a supply that shares ground with the printer put
    supply + on board GND, which shorted through the Hackerboard ground.
    - J3 pin 1 and J4 pins 1-2 move to a new net, HB_GND, which reaches
    board GND only through F2 (Bel 0ZCG0010FF2C, 0.1 A, 60 V, 100 A).
    - R7-R10 rise to 10 kOhm to limit pin current while F2 is tripped.
    - A DRC rule keeps copper 3.75 mm clear of the M3 mounting holes.
    - The Mouser order rounds passives up to the 10-piece break with spares.
    - Spec and README now cover source fusing, mounting, hot-plug
    overshoot, strip shorts and the remaining reverse-polarity limits.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
    [led-pwm-4bit-bom.csv, led-pwm-4bit-mouser-order.csv, led-pwm-4bit.kicad_pcb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]
2026-10-08 pcb: Stitch the GND pours and give C6 a solid ground
    Add 32 tented 0.6/0.3 mm GND vias: one beside each GND pad, two
    between C9 and U1, and a sparse grid. The +24V and +3V3 tracks split
    the top pour into regions joined by thin necks; the vias tie each
    region to the bottom pour. They stay clear of the unrouted connections
    and the mounting-hole keepout, and no drill lands on silkscreen.
    C6 pad 2 had a single thermal spoke. A 0.5 mm track now joins it to a
    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
    [led-pwm-4bit.kicad_pcb]
